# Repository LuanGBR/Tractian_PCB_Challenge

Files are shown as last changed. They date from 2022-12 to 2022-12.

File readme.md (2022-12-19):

# Tractian Technical Challenge

## The problem

Develop a full wireless communication system. 

**Requirements:**
- Send a file of size 500kB;
- The devices should be 100m apart open-air;
- At least  one of the devices must be battery powered.

## The solution

### 1. Sketch it up!

The first challenge was to choose the communication protocoto match the requeriments. Wi-Fi, Zig-Bee and bluetooth was considered, but LoRa has been chosen as the communication protocol. The main reason for this choice was the energy requirement, LoRa is extremely energy-efficient and also capable of sending a 500kB through a 100m gap in a resonable amount of time.

Doing some research about LoRa on IoT forums I dicovered a new product from Microchip, the SAM R34 module. It is a System In a Package that contains the microprocessor and the LoRa module in a single chip. Besides this advantages, I preferred this solution because I've already make other projects with Microchips products., and i've had good impressions.

<!-- imagem do chip -->


The next step was to dive deep into the SiP Datasheet and documentation, to understand the specificities of this microprocessor. After that I was capable of sketching a schematic. It is in the repository named  <!-- nome do arquivo -->

**Microcontroller**


**RF circuit**


**Oscillators**


**learnings:**

- When dealing with RF circuits it is import to add some decoupling capacitors to minimize interference, they act as low-pass filters and is import to place it right next to the chip terminals

### 2. It’s layout time
 
With the schematic on hand the PCB project started. As PCB design guidelines (and the SAMR34 datasheet) suggest boards with analog electronic, specially RF electronic, should be at least 4 layers, one being a ground plane, another being the power layer. Also, it's good to physically apart the components by their function, specially the RF components that can suffer from interference. 



#### Controlled Impedance
To reduce reflectance of the signal on analog signal tracks it is import to tune the track impedance to match the internals of the RF module and antenna. In this implementation, 50$\Omega$. 

For reference, the PCB dimensions and tolerances are from JCLPCB JLC7628 Stackup.

|  Min. Trace width/Spacing  | Min. Via  | Min. BGA |
|---:|---:|---:|
|3.5mil|0.2mm|0.25mm

**Prepeg/Core dieletric constant:**  4.6

**Stacking:**
| Layer | Material Type | Thickness |
|---|---|---|
| Top Layer1 | Copper | 0.035 mm  |
| Prepreg | 7628*1 | 0.2104 mm |
| Inner Layer2  | Copper | 0.0152 mm |
| Core | Core | 1.065 mm  |
| Inner Layer3  | Copper | 0.0152 mm |
| Prepreg | 7628*1 | 0.2104 mm |
| Bottom Layer4 | Copper | 0.035 mm  |
| **Total**| --|1.5862 mm|



Therefore, all RF tracks were made with this tuned impedance in mind.

#### Final Result

**Layers except GND plane**



**3D view**


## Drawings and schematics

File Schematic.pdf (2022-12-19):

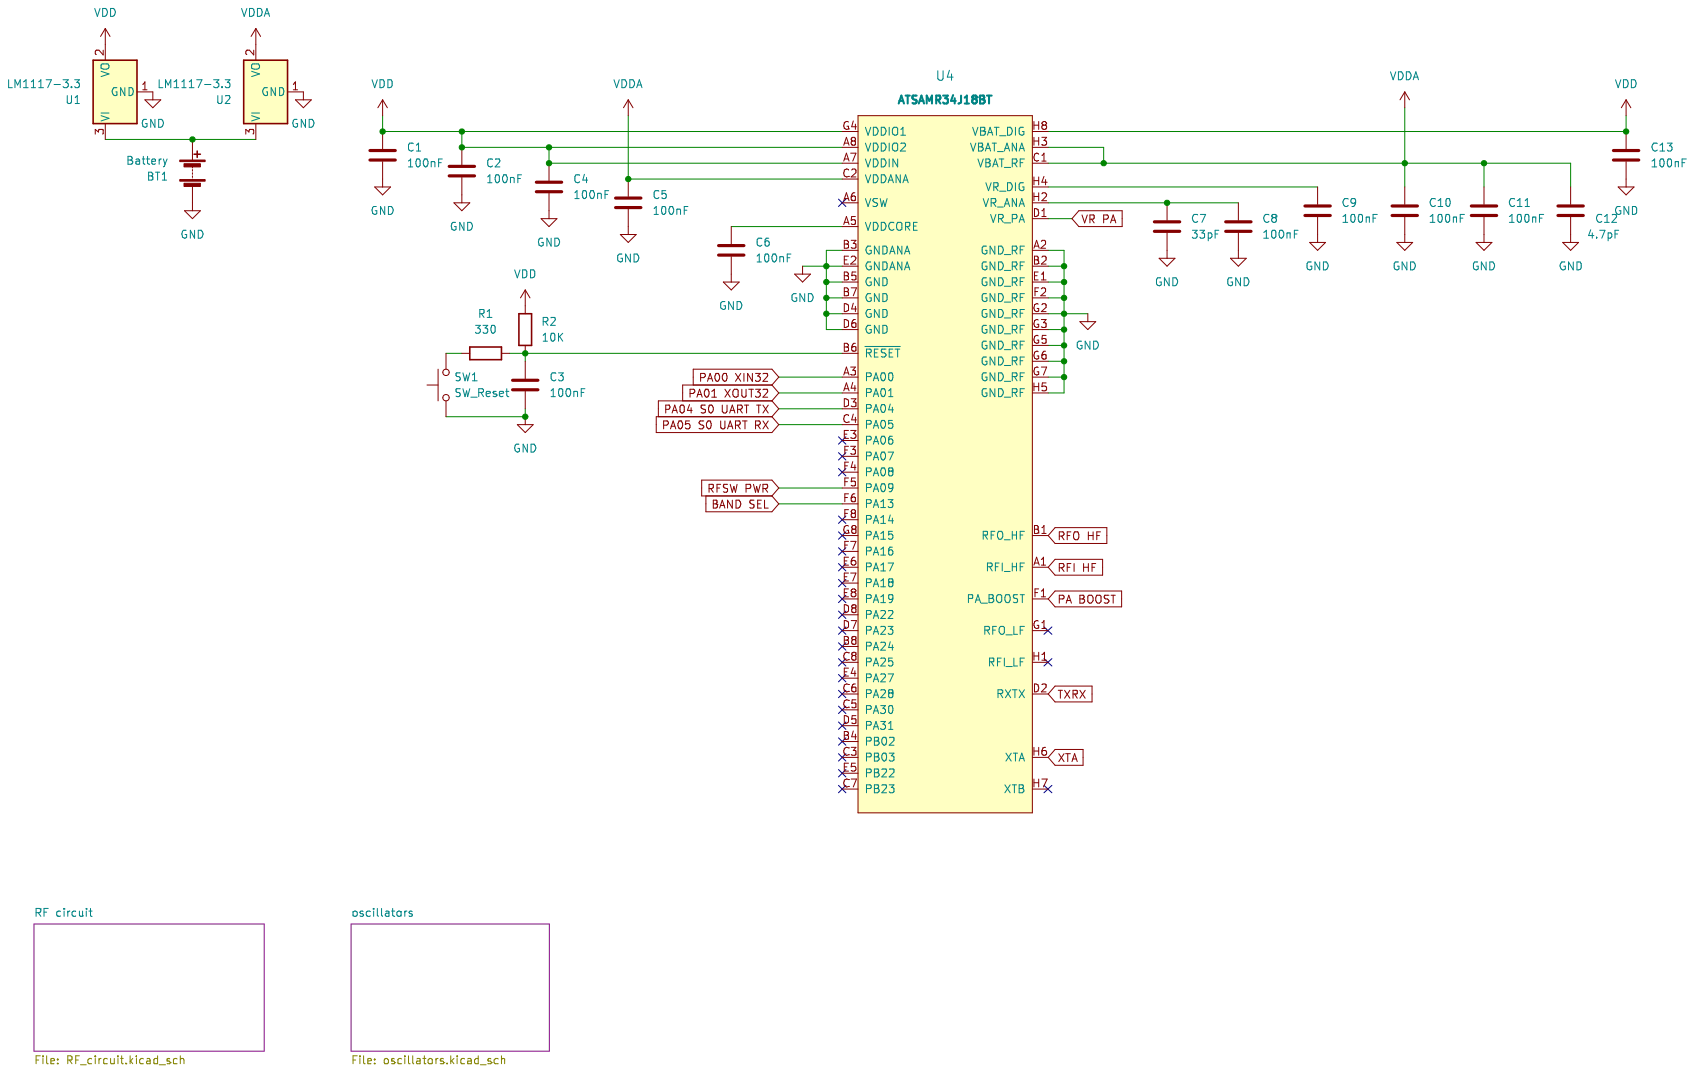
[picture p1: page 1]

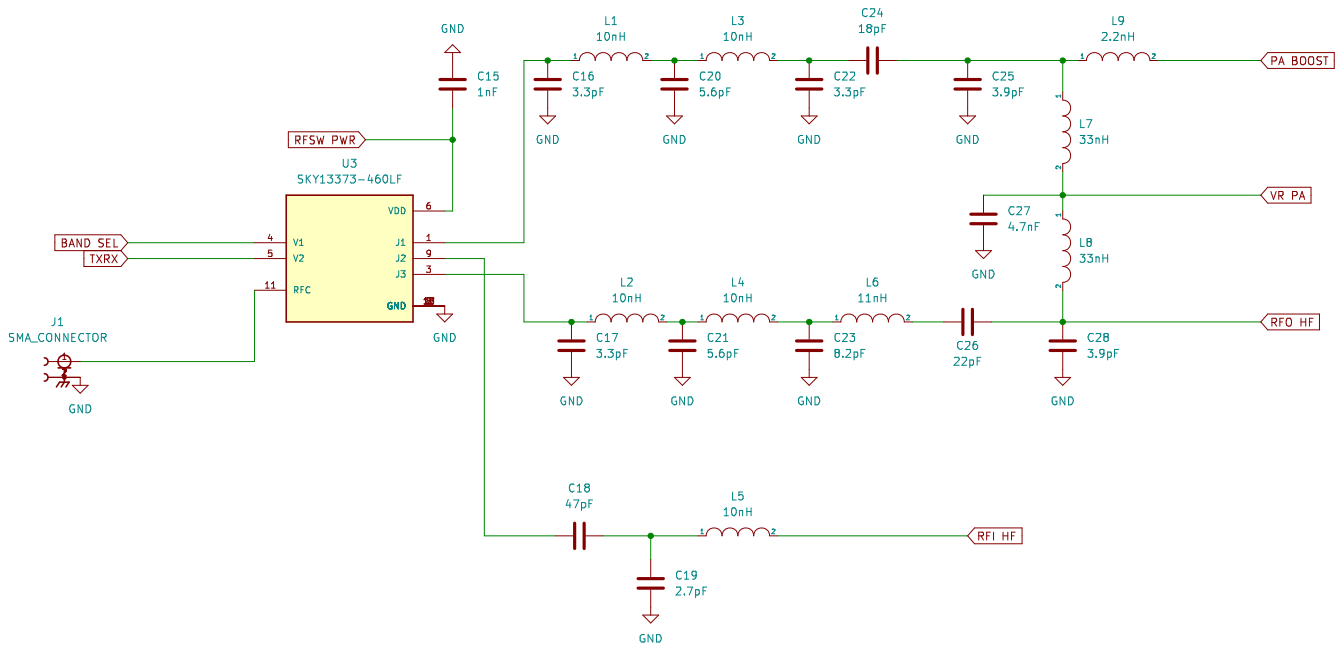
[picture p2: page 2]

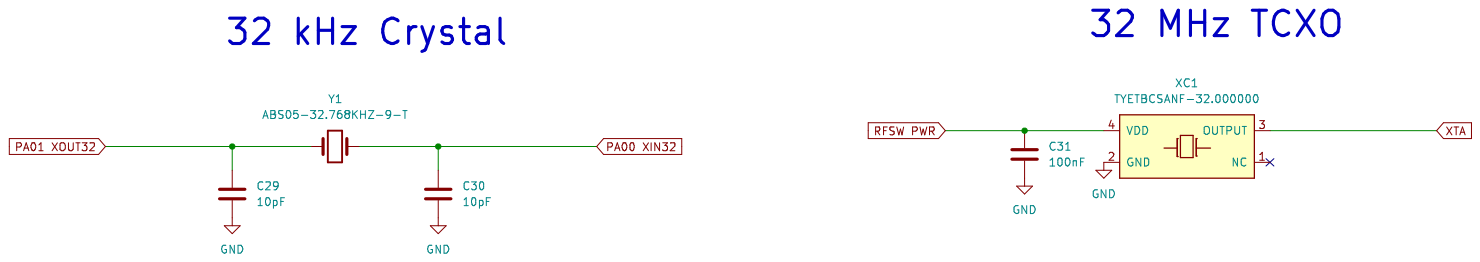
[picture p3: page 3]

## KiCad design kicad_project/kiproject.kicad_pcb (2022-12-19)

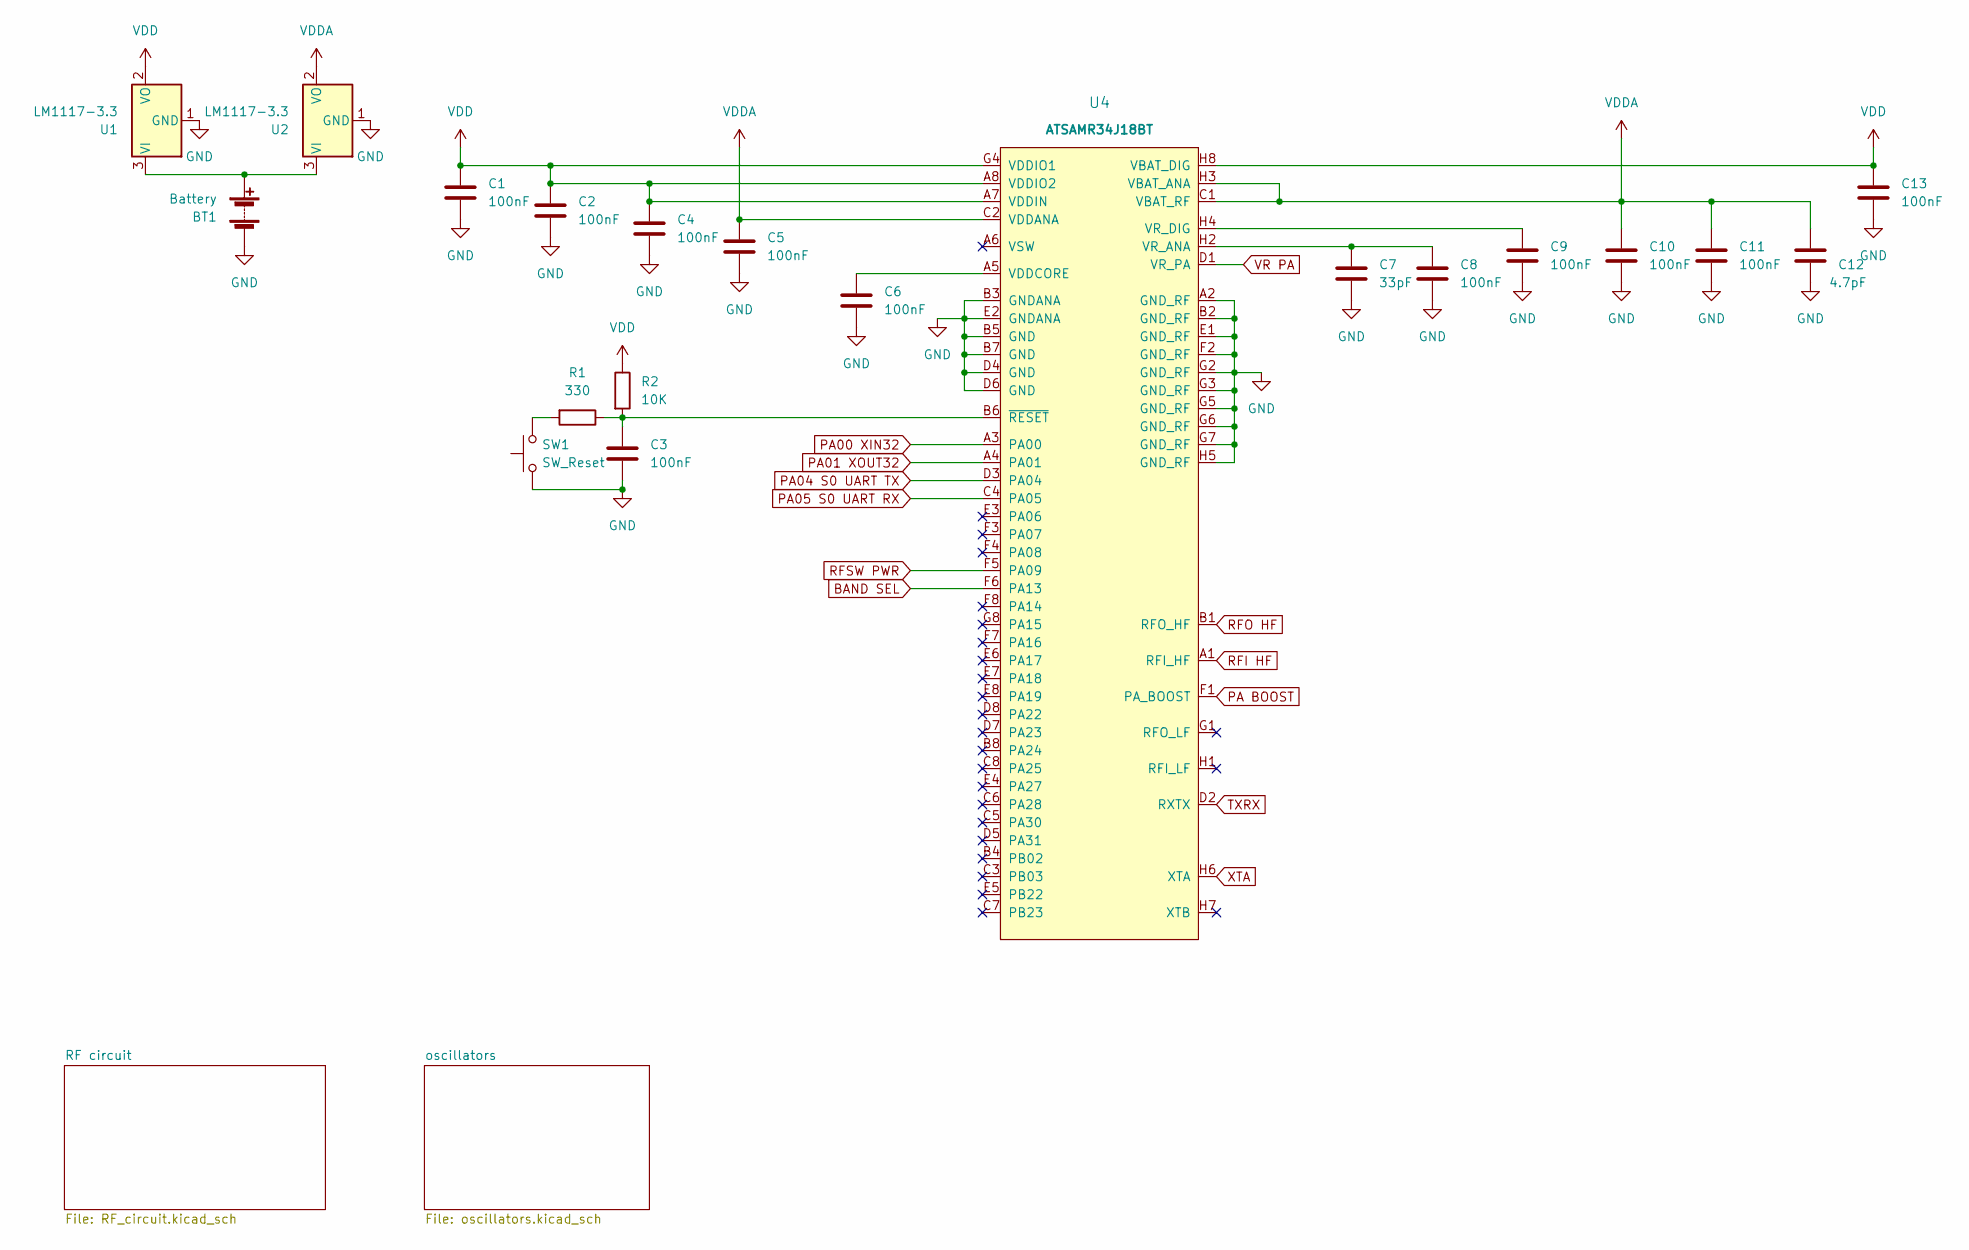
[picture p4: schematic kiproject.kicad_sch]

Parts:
BT1: Battery; BatteryHolder_Eagle_12BH611-GR
C1, C2, C3, C4, C5, C6, C8, C9, C10, C11, C13: 100nF; C_0201_0603Metric
C7: 33pF; C_0201_0603Metric
C12: 4.7pF; C_0201_0603Metric
R1: 330; C_0402_1005Metric
R2: 10K; C_0402_1005Metric
SW1: SW_Reset; SW_PUSH_6mm
U1, U2: LM1117-3.3; TO254P470X1016X2222-3P
U4: ATSAMR34J18BT; ATSAMR34J18BT-I&slash_7JX

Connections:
BAND SEL: U4.F6 (PA13); also elsewhere on the board
GND: BT1.2 (-), C1.2, C2.2, C3.2, C4.2, C5.2, C6.2, C7.2, C8.2, C9.2, C10.2, C11.2, C12.2, C13.2, SW1.1, U1.1 (GND), U2.1 (GND), U4.A2 (GND_RF), U4.B2 (GND_RF), U4.B3 (GNDANA), U4.B5 (GND), U4.B7 (GND), U4.D4 (GND), U4.D6 (GND), U4.E1 (GND_RF), U4.E2 (GNDANA), U4.F2 (GND_RF), U4.G2 (GND_RF), U4.G3 (GND_RF), U4.G5 (GND_RF), U4.G6 (GND_RF), U4.G7 (GND_RF), U4.H5 (GND_RF); also elsewhere on the board
unnamed: BT1.1 (+), U1.3 (VI), U2.3 (VI)
unnamed: C3.1, R1.1, R2.2, U4.B6 (~RESET)
unnamed: C6.1, U4.A5 (VDDCORE)
unnamed: C7.1, C8.1, U4.H2 (VR_ANA)
unnamed: C9.1, U4.H4 (VR_DIG)
unnamed: R1.2, SW1.2
PA00 XIN32: U4.A3 (PA00); also elsewhere on the board
PA01 XOUT32: U4.A4 (PA01); also elsewhere on the board
PA04 S0 UART TX: U4.D3 (PA04)
PA05 S0 UART RX: U4.C4 (PA05)
PA BOOST: U4.F1 (PA_BOOST); also elsewhere on the board
RFI HF: U4.A1 (RFI_HF); also elsewhere on the board
RFO HF: U4.B1 (RFO_HF); also elsewhere on the board
RFSW PWR: U4.F5 (PA09); also elsewhere on the board
TXRX: U4.D2 (RXTX); also elsewhere on the board
VDD: C1.1, C2.1, C4.1, C13.1, R2.1, U1.2 (VO), U4.A7 (VDDIN), U4.A8 (VDDIO2), U4.G4 (VDDIO1), U4.H8 (VBAT_DIG)
VDDA: C5.1, C10.1, C11.1, C12.1, U2.2 (VO), U4.C1 (VBAT_RF), U4.C2 (VDDANA), U4.H3 (VBAT_ANA)
VR PA: U4.D1 (VR_PA); also elsewhere on the board
XTA: U4.H6 (XTA); also elsewhere on the board

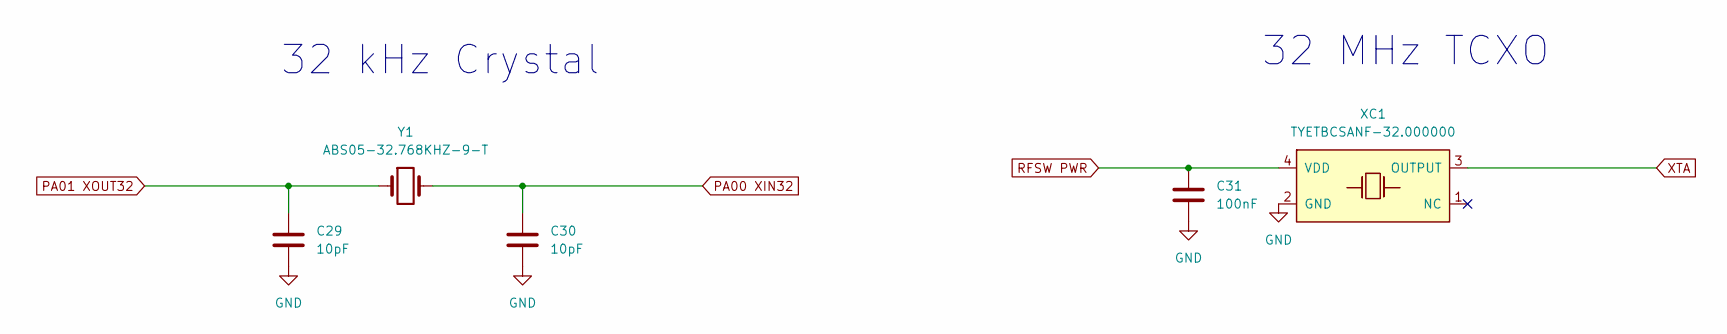
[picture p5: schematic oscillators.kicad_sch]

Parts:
C29, C30: 10pF; C_0201_0603Metric
C31: 100nF; C_0603_1608Metric
XC1: TYETBCSANF-32.000000; Oscilator_2.5x2.0
Y1: ABS05-32.768KHZ-9-T; ABS0532768KHZ9T

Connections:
GND: C29.2, C30.2, C31.2, XC1.2 (GND); also elsewhere on the board
PA00 XIN32: C30.1, Y1.2; also elsewhere on the board
PA01 XOUT32: C29.1, Y1.1; also elsewhere on the board
RFSW PWR: C31.1, XC1.4 (VDD); also elsewhere on the board
XTA: XC1.3 (OUTPUT); also elsewhere on the board

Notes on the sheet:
32 kHz Crystal
32 MHz TCXO

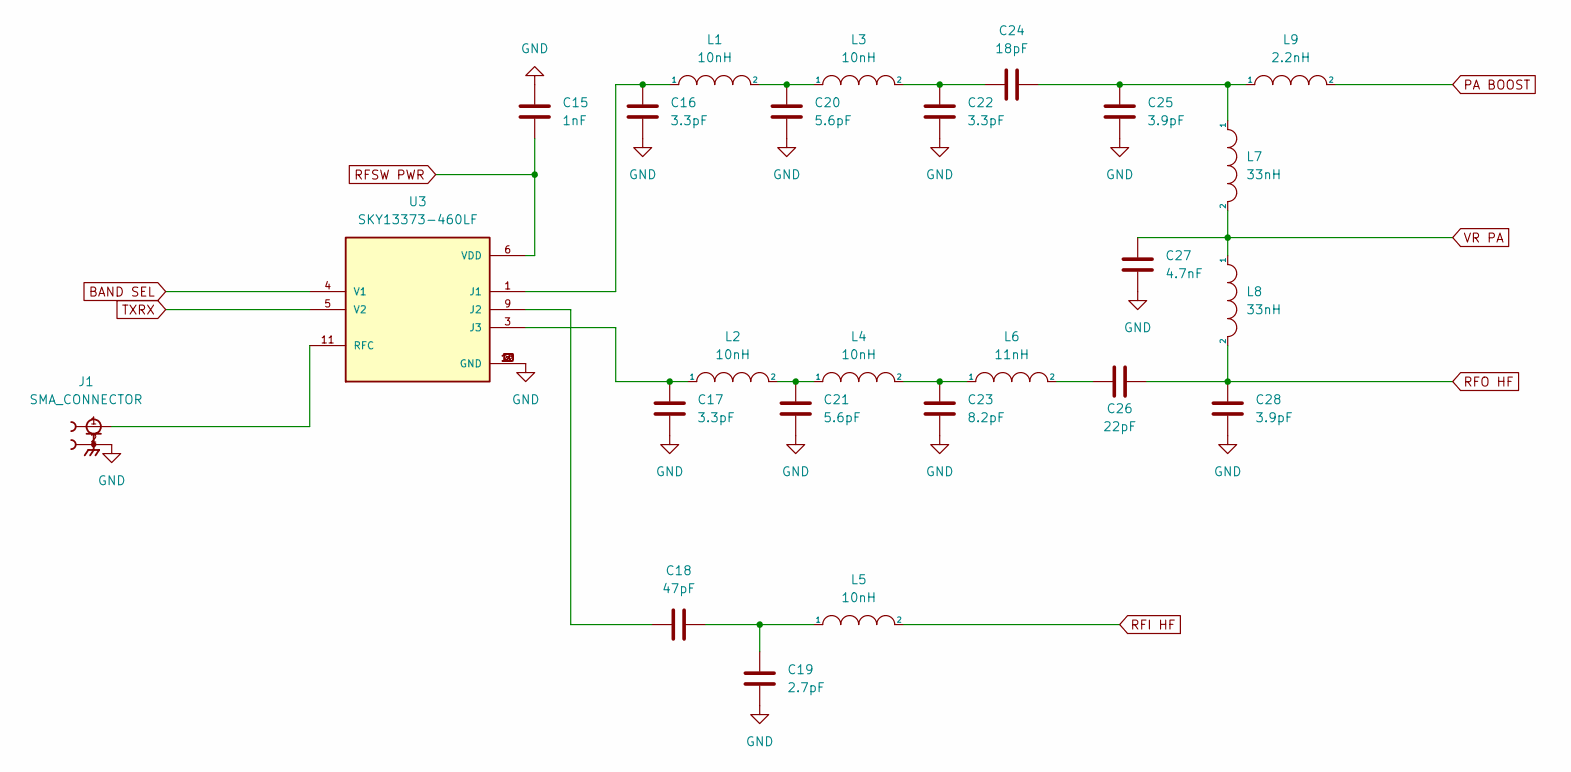
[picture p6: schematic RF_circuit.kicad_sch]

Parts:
C15: 1nF; C_0201_0603Metric
C16, C17, C22: 3.3pF; C_0201_0603Metric
C18: 47pF; C_0201_0603Metric
C19: 2.7pF; C_0201_0603Metric
C20, C21: 5.6pF; C_0201_0603Metric
C23: 8.2pF; C_0201_0603Metric
C24: 18pF; C_0201_0603Metric
C25, C28: 3.9pF; C_0201_0603Metric
C26: 22pF; C_0201_0603Metric
C27: 4.7nF; C_0201_0603Metric
J1: SMA_CONNECTOR; SMA_J_P_X_ST_EM1_EdgeMount; PARTREV 1.3
L1, L2, L3, L4, L5: 10nH; L_0201_0603Metric
L6: 11nH; L_0201_0603Metric
L7, L8: 33nH; L_0201_0603Metric
L9: 2.2nH; L_0201_0603Metric
U3: SKY13373-460LF; QFN50P200X200X65-13N; PARTREV May 6, 2016

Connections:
BAND SEL: U3.4 (V1); also elsewhere on the board
GND: C15.2, C16.2, C17.2, C19.2, C20.2, C21.2, C22.2, C23.2, C25.2, C27.2, C28.2, J1.2, U3.2 (GND), U3.7 (GND), U3.8 (GND), U3.10 (GND), U3.12 (GND), U3.13 (GND); also elsewhere on the board
unnamed: C16.1, L1.1, U3.1 (J1)
unnamed: C17.1, L2.1, U3.3 (J3)
unnamed: C18.1, U3.9 (J2)
unnamed: C18.2, C19.1, L5.1
unnamed: C20.1, L1.2, L3.1
unnamed: C21.1, L2.2, L4.1
unnamed: C22.1, C24.1, L3.2
unnamed: C23.1, L4.2, L6.1
unnamed: C24.2, C25.1, L7.1, L9.1
unnamed: C26.1, L6.2
unnamed: J1.1, U3.11 (RFC)
PA BOOST: L9.2; also elsewhere on the board
RFI HF: L5.2; also elsewhere on the board
RFO HF: C26.2, C28.1, L8.2; also elsewhere on the board
RFSW PWR: C15.1, U3.6 (VDD); also elsewhere on the board
TXRX: U3.5 (V2); also elsewhere on the board
VR PA: C27.1, L7.2, L8.1; also elsewhere on the board

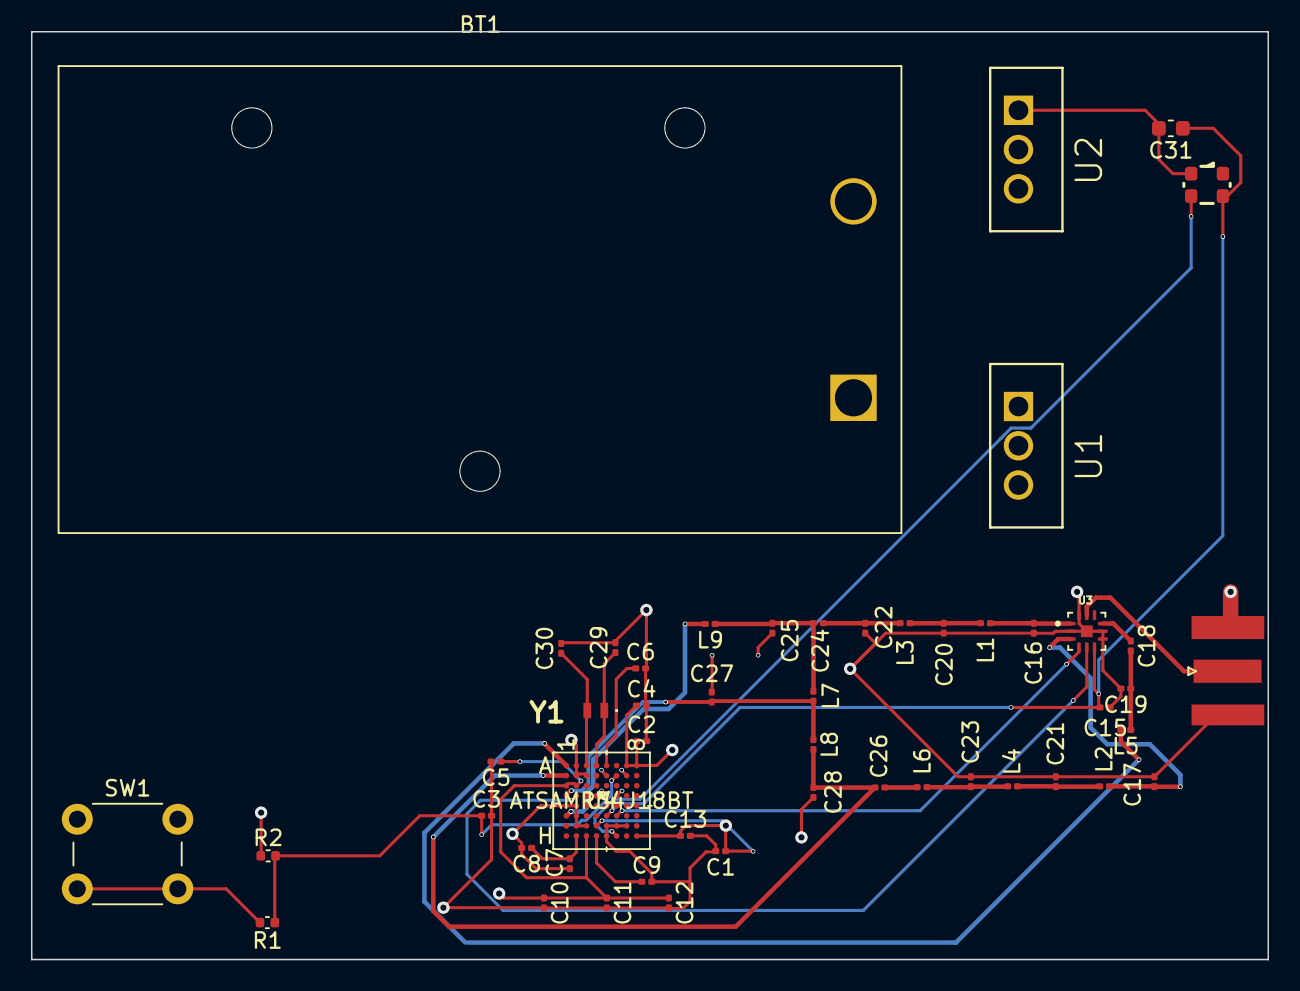
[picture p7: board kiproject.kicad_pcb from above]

Board: 4 copper layers, 80.0 x 60.0 mm, 50 parts (0 on the bottom side), 30 nets.

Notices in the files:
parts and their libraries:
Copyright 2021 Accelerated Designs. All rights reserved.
